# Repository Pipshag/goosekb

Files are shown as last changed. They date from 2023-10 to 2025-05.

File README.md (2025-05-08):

# Goose  38-key split wireless keyboard
Goose is a keyboard built with the help of [Ergogen](https://github.com/ergogen/ergogen).
This means that it's really simple to edit */config.yaml* and generate your own design, stagger and splay.
The KiCad PCBs are located in *pcb/* and contains the pcb, plate and bottom boards.
Use them to either manufacture directly or take leads from how I routed the pcb if you create your own. 

## Description
Wireless 38-key split and reversible keyboard with two rotary encoders, no support for button/press on these.
Plate is optional, but I'm using 3-pin switches which does almost make plates mandatory.
Batteries soldered directly to PCB, bought batteries with protection against shorts.
All PCBs are reversible.

Stagger and splay according to my hands, helped by [Ergopad](https://pashutk.com/ergopad/).
Artwork generated with Midjourney AI. Not really gooses but goose-like? :D

## Variations
See branches for keyswitch variations (choc and mx).

## Images
Final, completed, keyboard (left side).
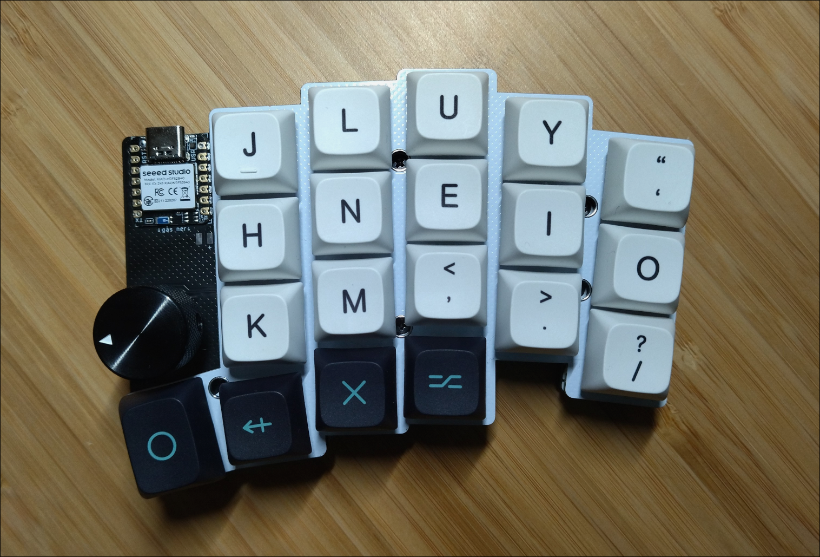
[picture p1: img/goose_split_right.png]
Goose completed, right side


Ergogen generated layout.
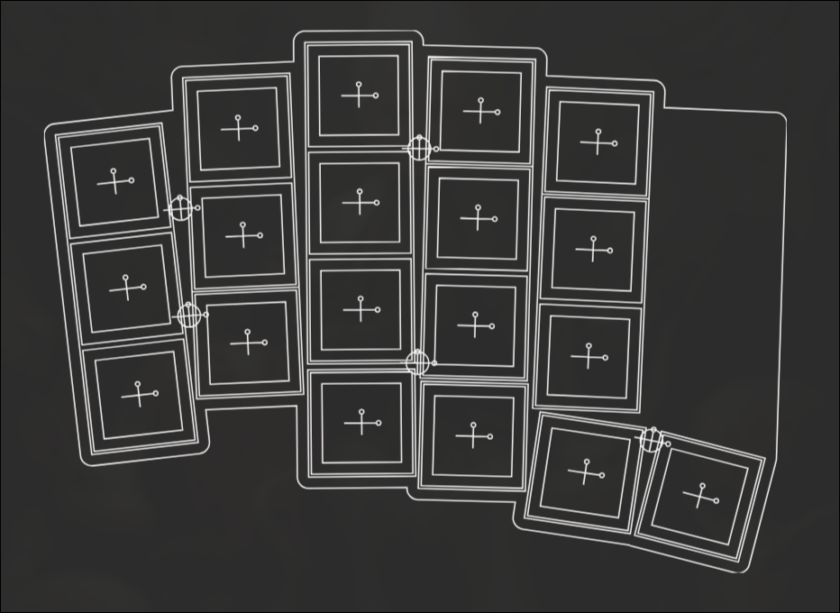
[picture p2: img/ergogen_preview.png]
Ergogen


Routed PCB, KiCad preview.
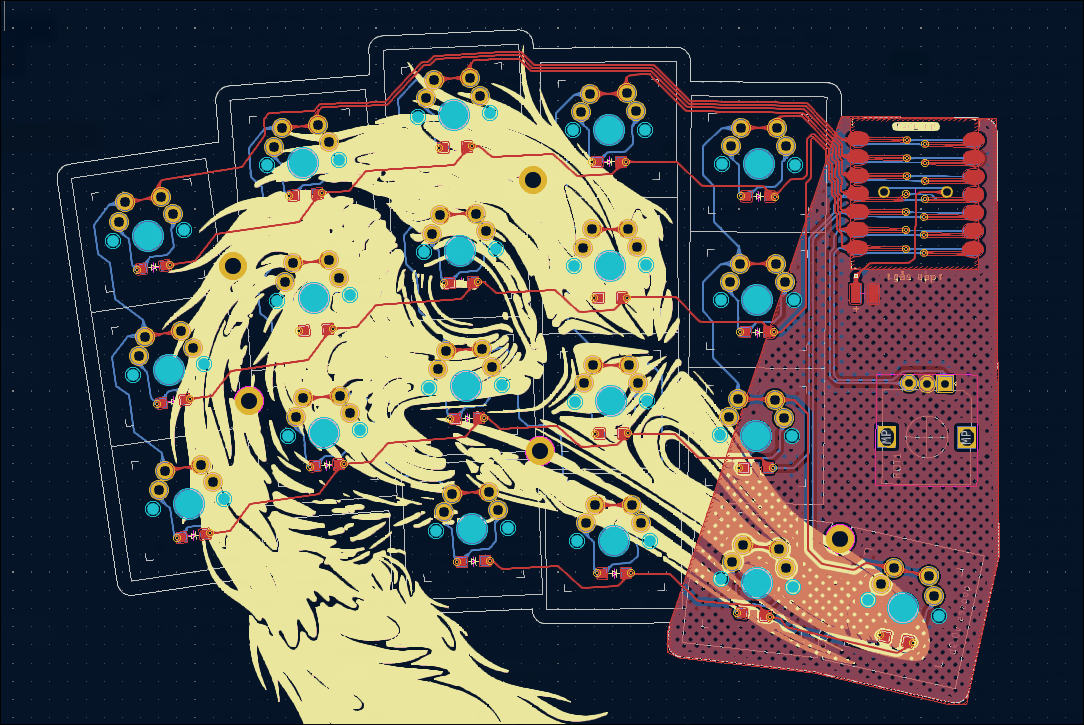
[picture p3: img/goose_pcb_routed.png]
KiCad routed PCB


## Materials
- 2 x Xiao Seeed nRF52840
- 2 x EC12 rotary encoders
- 2 x Knobs for rotary encoder
- 38 x Cherry MX switches
- 38 x SOD-123 Diodes
- 2 x LiPo batteries

## Firmware
ZMK firmware for wireless support. Contained in *firmware/*, includes build-script.

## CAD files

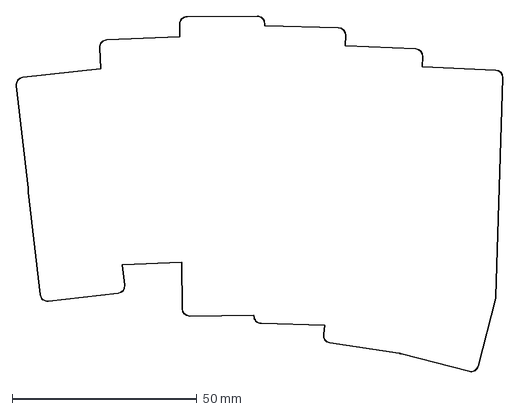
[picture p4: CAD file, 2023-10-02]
generated/outlines/pcb.dxf
131.8 x 96.3 mm

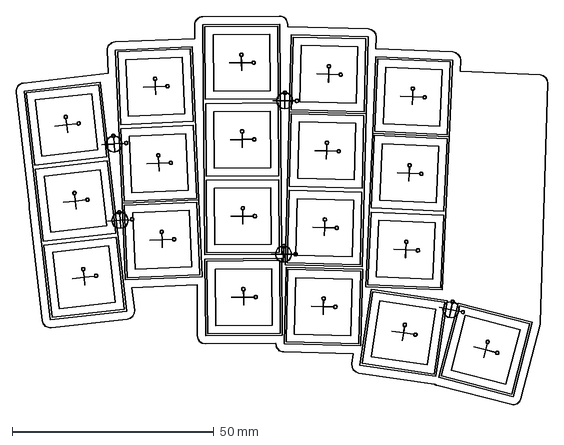
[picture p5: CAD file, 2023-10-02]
generated/outlines/preview.dxf
131.8 x 96.3 mm

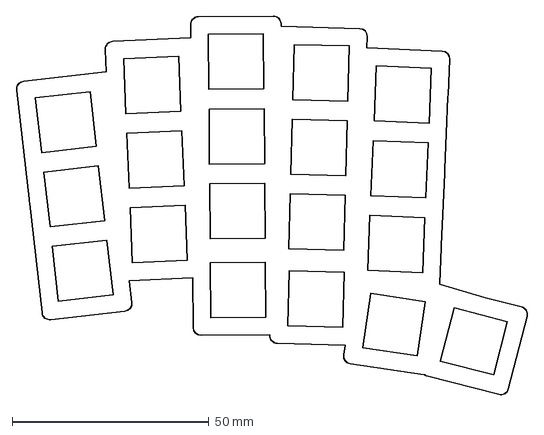
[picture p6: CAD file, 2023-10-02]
generated/outlines/plate.dxf
130.0 x 96.3 mm

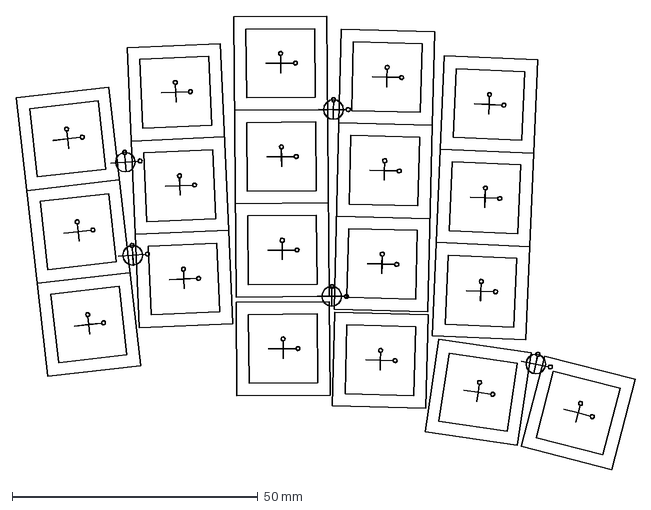
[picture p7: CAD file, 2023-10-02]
generated/outlines/debug_points.dxf
125.9 x 92.3 mm

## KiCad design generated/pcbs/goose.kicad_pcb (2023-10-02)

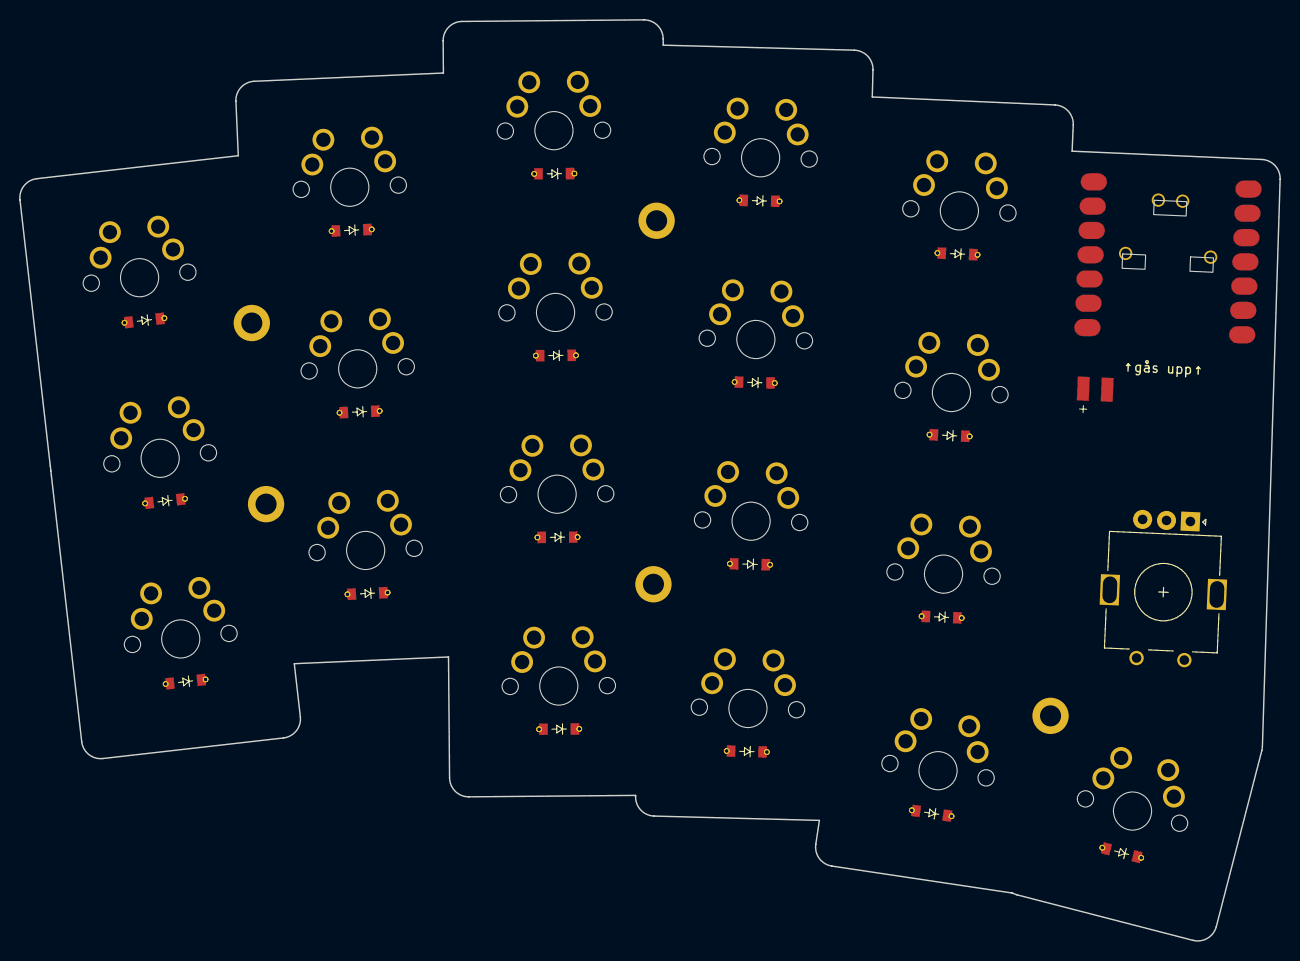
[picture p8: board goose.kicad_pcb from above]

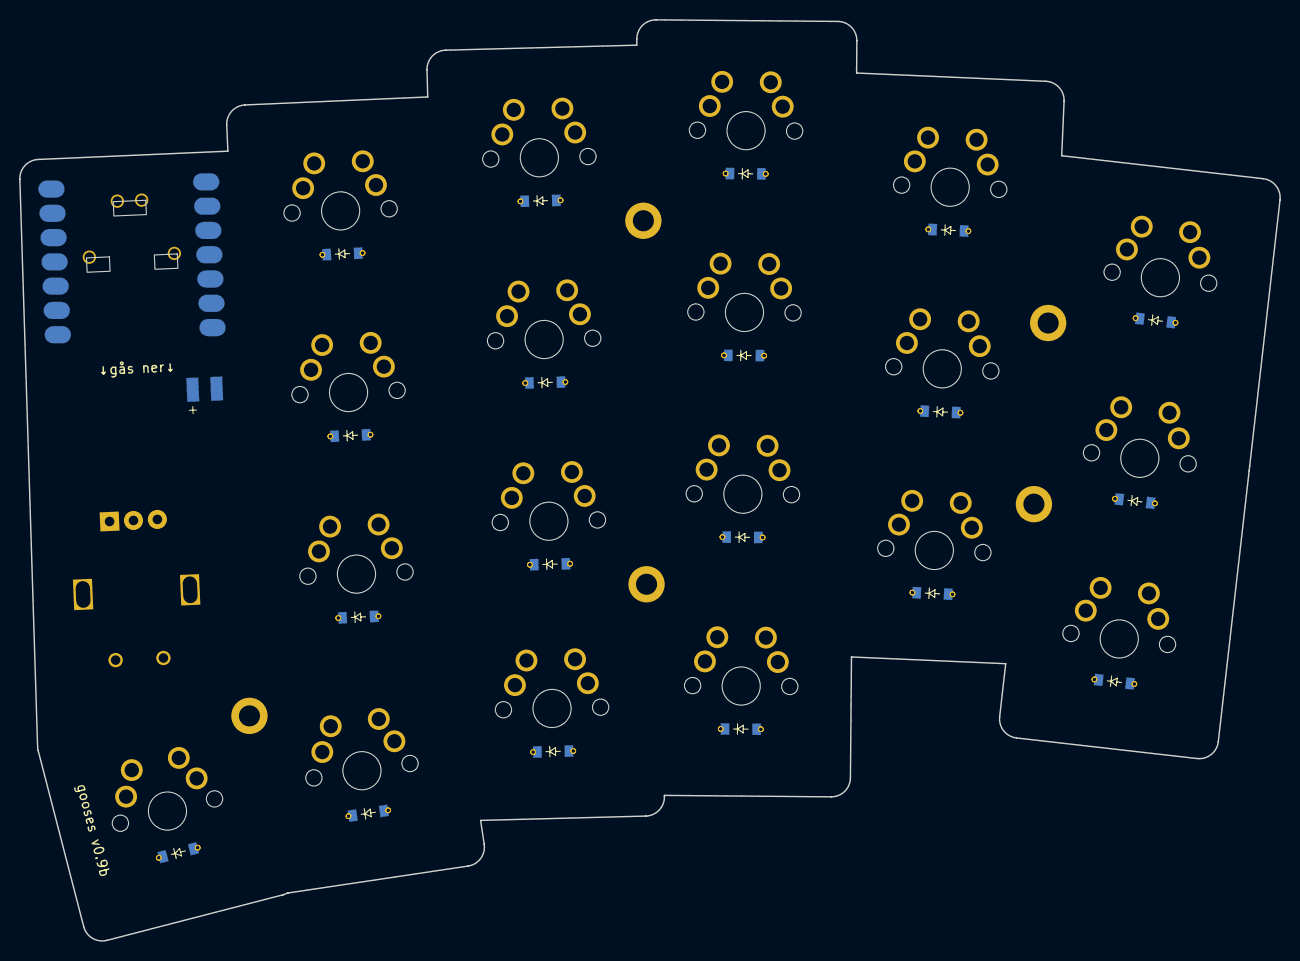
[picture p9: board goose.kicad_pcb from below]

Board: 2 copper layers, 131.7 x 96.3 mm, 65 parts (19 on the bottom side), 32 nets, no tracks yet.

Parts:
Di1, Di2, Di3, Di4, Di5, Di6, Di7, Di8, Di9, Di10, Di11, Di12, Di13, Di14, Di15, Di16, Di17, Di18, Di19, Di20, Di21, Di22, Di23, Di24, Di25, Di26, Di27, Di28, Di29, Di30, Di31, Di32, Di33, Di34, Di35, Di36, Di37, Di38: D_SOD-123
H1, H2, H3, H4, H5: mounting_hole
MCU1: xiao-ble-smd-reversible
PAD1: pads
ROT1: rotary_encoder
S1, S2, S3, S4, S5, S6, S7, S8, S9, S10, S11, S12, S13, S14, S15, S16, S17, S18, S19: MX

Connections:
BAT+: MCU1.19, PAD1.1, PAD1.2
C0: MCU1.1, S1.1, S2.1, S3.1
C0_R0: Di3.2, Di22.2, S3.2
C0_R1: Di2.2, Di21.2, S2.2
C0_R2: Di1.2, Di20.2, S1.2
C1: MCU1.2, S4.1, S5.1, S6.1, S16.1
C1_R0: Di6.2, Di25.2, S6.2
C1_R1: Di5.2, Di24.2, S5.2
C1_R2: Di4.2, Di23.2, S4.2
C1_R3: Di16.2, Di35.2, S16.2
C2: MCU1.3, S7.1, S8.1, S9.1, S17.1
C2_R0: Di9.2, Di28.2, S9.2
C2_R1: Di8.2, Di27.2, S8.2
C2_R2: Di7.2, Di26.2, S7.2
C2_R3: Di17.2, Di36.2, S17.2
C3: MCU1.4, S10.1, S11.1, S12.1, S18.1
C3_R0: Di12.2, Di31.2, S12.2
C3_R1: Di11.2, Di30.2, S11.2
C3_R2: Di10.2, Di29.2, S10.2
C3_R3: Di18.2, Di37.2, S18.2
C4: MCU1.5, S13.1, S14.1, S15.1, S19.1
C4_R0: Di15.2, Di34.2, S15.2
C4_R1: Di14.2, Di33.2, S14.2
C4_R2: Di13.2, Di32.2, S13.2
C4_R3: Di19.2, Di38.2, S19.2
ENCA: MCU1.8, ROT1.A
ENCB: MCU1.9, ROT1.B
GND: MCU1.13, MCU1.17, PAD1.1, PAD1.2, ROT1.C
R0: Di3.1, Di6.1, Di9.1, Di12.1, Di15.1, Di22.1, Di25.1, Di28.1, Di31.1, Di34.1, MCU1.6
R1: Di2.1, Di5.1, Di8.1, Di11.1, Di14.1, Di21.1, Di24.1, Di27.1, Di30.1, Di33.1, MCU1.7
R2: Di1.1, Di4.1, Di7.1, Di10.1, Di13.1, Di20.1, Di23.1, Di26.1, Di29.1, Di32.1, MCU1.11
R3: Di16.1, Di17.1, Di18.1, Di19.1, Di35.1, Di36.1, Di37.1, Di38.1, MCU1.10

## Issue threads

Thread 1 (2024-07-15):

HowTo: Plate

auryn31, 2024-07-15:
Love this keyboard, currently building one myself and taking some inspiration.

How did you generate the plate for the key switches? :)

Greetings

auryn31, 2024-07-17:
Found it in the history :)
Thanks

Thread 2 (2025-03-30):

Battery placement

jacobsamlarose, 2025-03-30:
Love this design. Out of interest: where did you place the batteries in your build? Between the PCB and the bottom plate?

Closed 2025-04-01.

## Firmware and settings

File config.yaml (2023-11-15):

units:
  # Key and keycap measures
  kx: cx # spacing between key centers (X-axis)
  ky: cy # spacing between key centers (Y-axis)  kp: 19 # padding (default: 19)
  ks: 19 # spread (deafult: 19)
  kp: cx
  kcow: 13.8 # key cutout hole width (cherry: 14, choc: 13.8)
  kcoh: 13.8 # key cutout hole height (cherry: 14, choc: 13.8)
  keycw: 17.5 # keycap width (cherry: 18, choc: 17.5)
  keych: 16.5 # keycap height (cherry: 18, choc: 16.5)
  $default_autobind: 5
points:
  zones:
    matrix:
      key:
        padding: cy
        spread: ks
        tags:
          - key
      anchor:
        shift: [160, -175]
        rotate: 0
      rotate: 6.5
      rows:
        R2:
          row_net: R2
        R1:
          row_net: R1
        R0:
          row_net: R0
      columns:
        C0:
          key:
            column_net: C0
            stagger: 6
            splay: 0
        C1:
          key:
            column_net: C1
            splay: -4
            stagger: 7
        C2:
          key:
            column_net: C2
            splay: -2
            stagger: 5
        C3:
          key:
            column_net: C3
            stagger: -3
            splay: -2
        C4:
          key:
            column_net: C4
            stagger: -5
            splay: -1
    thumbs:
      key:
        padding: cy
        spread: ks
        tags:
          - key
      anchor:
        ref: matrix_C2_R2
        shift: [0.5cx, -1.25cy]
      rows:
        R3:
          row_net: R3
      columns:
        C1:
          key:
            bind: [5,5,0,0]
            column_net: C1
            stagger: -1
            #shift: [-0, 0cy]
            splay: -2
        C2:
          key:
            bind: [5,5,0,0]
            column_net: C2
            splay: -8
            stagger: -2
            shift: [0.2cy, -0.15cy]
        C3:
          key:
            bind: [0,0,0,0]
            column_net: C3
            splay: -5
            stagger: -3
            shift: [0.35cy, -0cy]
            rotate: 270
    mountscrew_c0_top:
      anchor:
        ref.aggregate.parts:
          [matrix_C0_R0, matrix_C1_R0, matrix_C0_R1, matrix_C1_R1]
        shift: [0, 3]
      columns.screw.key.tags: [screw]
    mountscrew_c1_bottom:
      anchor:
        ref.aggregate.parts:
          [matrix_C0_R1, matrix_C1_R1, matrix_C0_R2, matrix_C1_R2]
      columns.screw.key.tags: [screw]
    mountscrew_c3_top:
      anchor:
        ref.aggregate.parts: [matrix_C2_R0, matrix_C3_R0]
        shift: [0, -3]
      columns.screw.key.tags: [screw]
    mountscrew_c2_bottom:
      anchor:
        ref.aggregate.parts: [matrix_C2_R2, matrix_C3_R2]
        shift: [0.1, -6]
      columns.screw.key.tags: [screw]
    mountscrew_c4_bottom:
      anchor:
        ref.aggregate.parts: [thumbs_C3_R3, thumbs_C2_R3, matrix_C4_R2]
        shift: [-2, -2]
      columns.screw.key.tags: [screw]
    mountscrew_c4_top:
      anchor: 
        ref: matrix_C4_R0
        shift: [0.5cx, -0.5cy]
      columns.screw.key.tags: [screw]
outlines:
  debug_points:
    - what: rectangle
      where: true
      size: [6, 0.01]
    - what: rectangle
      where: true
      size: [0.01, 4]
    - what: circle
      where: true
      radius: 0.4
      adjust:
        shift: [3, 0]
    - what: circle
      where: true
      radius: 0.4
      adjust:
        shift: [0, 2]
    - what: rectangle
      where: [key]
      size: [cx, cy]
      operation: stack
    - what: rectangle
      where: [key]
      size: [kcow, kcoh]
      operation: stack
    - what: circle
      where: [screw]
      radius: 2
      operation: stack
  _switch_cutouts:
    - what: rectangle
      where: [key]
      size: [kcow, kcoh]
  _base:
    - what: rectangle
      where: [key]
      bound: true
      size: [cx, cy]
  _pcb_keyboard:
    - what: outline
      name: _base
    - what: polygon
      operation: add
      points:
        - ref: matrix_C4_R0
          shift: [1.65cx, 0.25cy]
        - ref: thumbs_C3_R3
          shift: [-0.5cx, 0.5cy]
        - ref: thumbs_C3_R3
          shift: [0.5cx, 0]
        - ref: matrix_C4_R0
          shift: [0, 0.25cy]
    - what: outline
      name: _pcb_keyboard
      expand: 1
      fillet: 0
  pcb:
    - what: outline
      name: _pcb_keyboard
  preview:
    - what: outline
      name: debug_points
    - what: rectangle
      where: [key]
      size: [keycw, keych]
      operation: stack
    - what: outline
      name: _switch_cutouts
      operation: stack
    - what: outline
      name: pcb
      operation: stack
pcbs:
  bottom:
    outlines:
      main.outline: pcb
    footprints:
      screws:
        what: custom/mounting_hole
        params:
        where: [screw]
  goose:
    outlines:
      main.outline: pcb
    footprints:
      switches:
        what: choc
        where:
          - /matrix/
          - /thumbs/
        params:
          keycaps: true
          reverse: true
          hotswap: false
          from: "{{column_net}}"
          to: "{{colrow}}"
      diodes_back:
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

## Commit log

2023-09-13 Initialize repo and WIP config of goosekb
    [_base.dxf, _pcb_tolerance.dxf, _switch_cutouts.dxf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]
2023-09-21 Almost finalized
    [debug_points.dxf, freerouting.dsn, goose.dsn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]
2023-09-24 Ok version
    [debug_points.dxf, goose.kicad_pcb, preview.dxf]
2023-09-29 Mirrored pcbs
    [debug_points.dxf, goose.kicad_pcb, goose_pcb_left.kicad_pcb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]
2023-10-02 Add initial ZMK firmware folders
    [bottom.kicad_pcb, debug_points.dxf, goose.kicad_pcb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]
2023-10-20 Stage and test for keymap editor
2023-10-20 fix utility-buttons
2025-05-08 Update README.md
    Clarified support for choc and mx switches
